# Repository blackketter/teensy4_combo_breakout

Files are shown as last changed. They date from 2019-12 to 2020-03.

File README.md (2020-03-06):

A combination breakout board with USB-A host and microSD connectors to mate with the [Teensy 4 Header Breakout Board](https://github.com/blackketter/teensy4_header_breakout).  Combines functionality of the [USB Host Breakout](https://github.com/blackketter/teensy4_usb_host_breakout) and the [SD Breakout](https://github.com/blackketter/teensy4_sd_breakout).

It's designed to mount above or below the Teensy 4 and Header Breakout board on a relatively tall header.

Designed in KiCad.

Notes:

- In progress: First cut, seems to work great.
- [OSHPark order](https://oshpark.com/shared_projects/X9b5MPJw)
- Download bom/ibom.html and view it with web browser to see bill of materials and placement information.
- The last pin on the right side provides an optional enable pin for the power management chip on digital pin 27.  For always-on, cut left trace and short right two pads.  
- The last pin on the left side provides SD card detect on digital pin 29.  Needs INPUT_PULLUP.  Cut the jumper to free up pin 29.

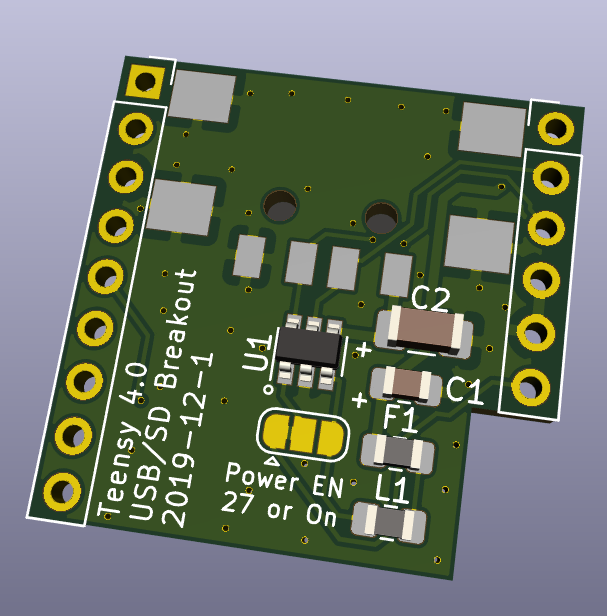
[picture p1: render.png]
breakout render

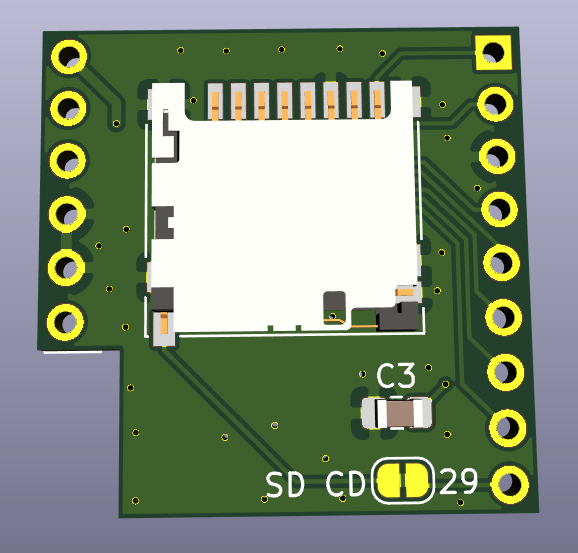
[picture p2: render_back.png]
breakout render_back

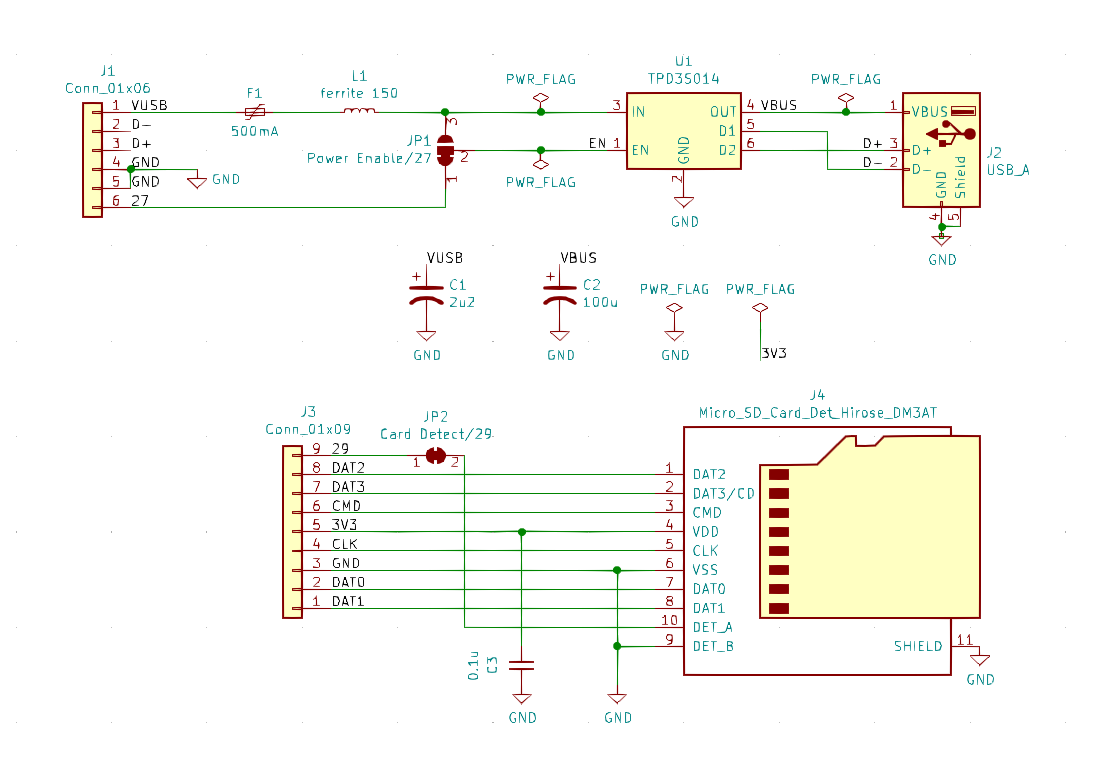
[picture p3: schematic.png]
schematic


Left Side Pinout:

1. 34/SD DAT1
2. 35/SD DAT0
3. GND
4. 36/SD CLK
5. 3.3V
6. 37/SD CMD
7. 38/SD DAT3
8. 39/SD DAT2
9. 29/Card Detect

Right Side Pinout:

1. VUSB
2. USB Host D-
3. USB Host D+
4. GND
5. GND
6. 27/EN

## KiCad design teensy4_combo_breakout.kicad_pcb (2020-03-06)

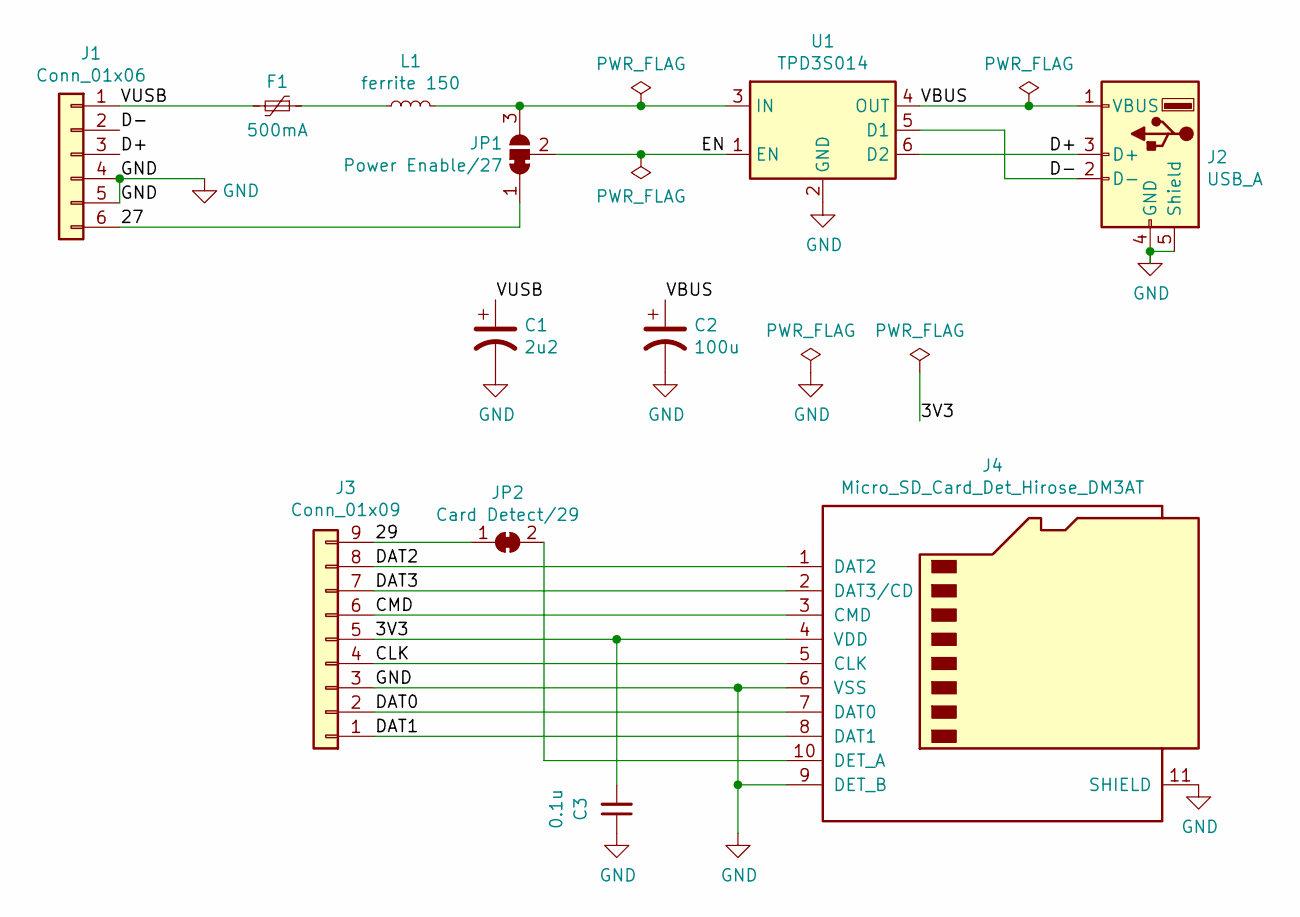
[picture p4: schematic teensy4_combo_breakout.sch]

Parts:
C1: 2u2; C_0805_2012Metric_Pad1.15x1.40mm_HandSolder; Digikey 1276-1188-1-ND
C2: 100u; C_1206_3216Metric_Pad1.42x1.75mm_HandSolder; Digikey ‎478-12404-1-ND‎
C3: 0.1u; C_0805_2012Metric_Pad1.15x1.40mm_HandSolder
F1: 500mA; L_0805_2012Metric_Pad1.15x1.40mm_HandSolder; Digikey 507-1813-1-ND
J1: Conn_01x06; PinHeader_1x06_P2.54mm_Vertical
J2: USB_A; USB_A_Receptacle_SMD_Wuerth_629104190121_Narrow; Digikey 732-11179-1-ND
J3: Conn_01x09; PinSocket_1x09_P2.54mm_Vertical
J4: Micro_SD_Card_Det_Hirose_DM3AT; microSD_HC_Hirose_DM3D-SF
JP1: Power Enable/27; SolderJumper-3_P1.3mm_Bridged12_RoundedPad1.0x1.5mm
JP2: Card Detect/29; SolderJumper-2_P1.3mm_Bridged_RoundedPad1.0x1.5mm
L1: ferrite 150; L_0805_2012Metric_Pad1.15x1.40mm_HandSolder; Digikey ‎490-1038-1-ND‎
U1: TPD3S014; SOT-23-6; Digikey 296-38835-1-ND

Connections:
/3V3: C3.2, J3.5, J4.4 (VDD)
/27: J1.6, JP1.1 (A)
/29: J3.9, JP2.1 (A)
/CLK: J3.4, J4.5 (CLK)
/CMD: J3.6, J4.3 (CMD)
/D+: J1.3, J2.3 (D+), U1.6 (D2)
/D-: J1.2, J2.2 (D-), U1.5 (D1)
/DAT0: J3.2, J4.7 (DAT0)
/DAT1: J3.1, J4.8 (DAT1)
/DAT2: J3.8, J4.1 (DAT2)
/DAT3: J3.7, J4.2 (DAT3/CD)
/EN: JP1.2 (C), U1.1 (EN)
/VBUS: C2.1, J2.1 (VBUS), U1.4 (OUT)
/VUSB: C1.1, F1.2, J1.1
GND: C1.2, C2.2, C3.1, J1.4, J1.5, J2.4 (GND), J2.5 (Shield), J3.3, J4.6 (VSS), J4.9 (DET_B), J4.11 (SHIELD), U1.2 (GND)
unnamed: F1.1, L1.1
unnamed: J4.10 (DET_A), JP2.2 (B)
unnamed: JP1.3 (B), L1.2, U1.3 (IN)

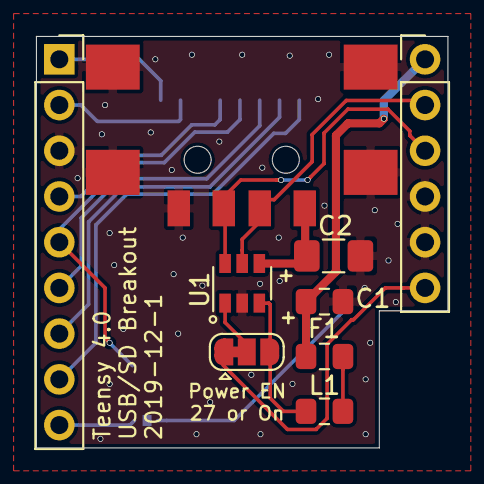
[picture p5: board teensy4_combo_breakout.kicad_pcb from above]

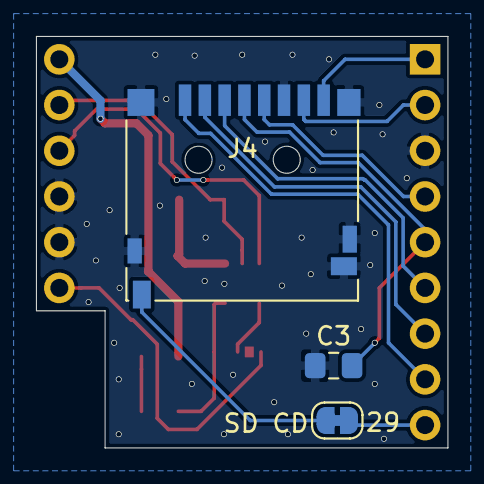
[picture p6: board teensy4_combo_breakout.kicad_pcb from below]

Board: 2 copper layers, 22.9 x 22.9 mm, 12 parts (3 on the bottom side), 18 nets.

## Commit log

2019-12-01 First version, ready for fabrication
    [teensy4_combo_breakout.kicad_pcb, teensy4_combo_breakout.sch]
2019-12-01 Fix board width
    [teensy4_combo_breakout.kicad_pcb]
2019-12-01 Revert "Fix board width"
    This reverts commit 50ad3588553998c4675441b0cbb2879693a946de.
    [teensy4_combo_breakout.kicad_pcb]
2020-03-06 Works great
    [teensy4_combo_breakout.kicad_pcb]
